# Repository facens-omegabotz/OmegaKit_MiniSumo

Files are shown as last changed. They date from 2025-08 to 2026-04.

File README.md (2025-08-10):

# OmegaKit MiniSumo

Repositório dedicado aos projetos de placas de circuito impresso (PCI) desenvolvidas para a categoria Mini Sumô - 500g (Autônomo | RC).

## OmegaKit FX50

Esta pasta diz respeito à versão da placa desenhada para os sensores FX50, da Fox Dynamics. A principal diferença deste desenho para o OmegaKit_RZ60 é a presença de LEDs para a sinalização de recepção de sinal.

[Datasheet FX50](https://github.com/luisf18/FXDevices/blob/main/Sensor_FXS50/Datasheet_FX_S50.pdf)

[Projeto esquemático OmegaKit FX50](./OmegaKit_FX50/OmegaKit_FX50.pdf)

## OmegaKit RZ60

Esta pasta diz respeito à versão da placa desenhada para os sensores RZ60s, da Sumozade. Esta placa liga diretamente os sensores à placa, visto que há LEDs na parte de trás dos sensores para sinalização de detecção.

[Informações RZ60s](https://sumozade.com/rz60s-digital-infrared-sensor--0-60-cm-)

[Projeto esquemático OmegaKit RZ60](./OmegaKit_RZ60/OmegaKit_RZ60.pdf)

## Omegakit Junior

Esta pasta diz respeito à versão da placa dedicada à nova categoria de mini sumô autônomo para juniores. Ela utiliza um Arduino Nano ao invés de um ESP32 DEVKIT V1, e possui 5 entradas analógicas para uso, visto que o Arduino Nano pode converter entradas analógicas em digitais de acordo com a necessidade.

[Projeto esquemático OmegaKit Junior](./OmegaKit_Junior/OmegaKit_Junior.pdf)

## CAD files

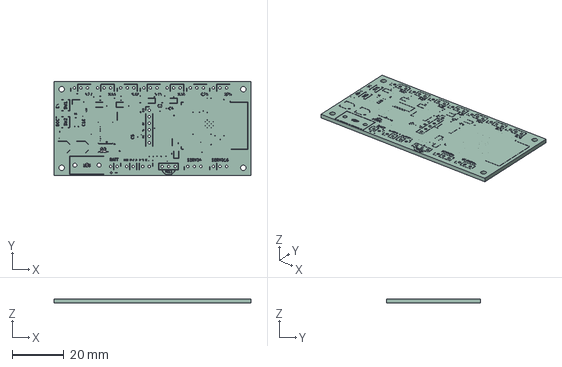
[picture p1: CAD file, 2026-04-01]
OmegaKit_ESP_Embarcado_Simplificado/OmegaKit_ESP_Embarcado_Simplificado.step
76.5 x 36.5 x 1.58 mm
OmegaKit_ESP_Embarcado_Simplificado_silkscreen
OmegaKit_ESP_Embarcado_Simplificado_PCB

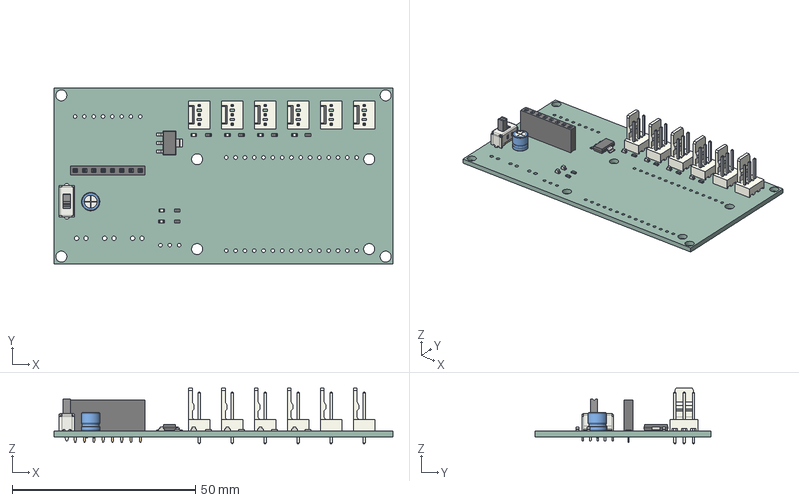
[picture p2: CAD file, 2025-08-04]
OmegaKit_FX50/OmegaKit_FX50.step
92.5 x 48.0 x 15.3 mm
Molex_KK-254_AE-6410-03A_1x03_P2.54mm_Vertical x 6
PinSocket_1x08_P2.54mm_Vertical
LED_0603_1608Metric x 6
R_0603_1608Metric x 6
SOT-223
C_Radial_D5.0mm_H5.0mm_P2.00mm
SW_Slide_SPDT_Straight_CK_OS102011MS2Q
OmegaKit_FX50_PCB

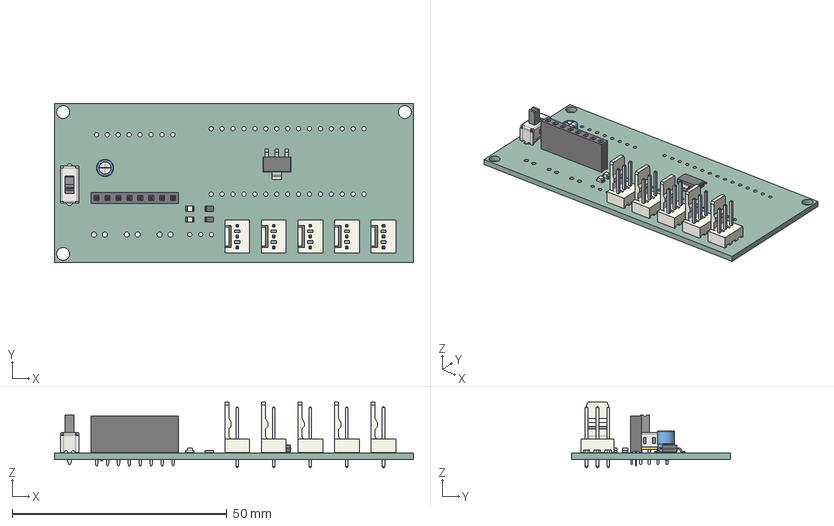
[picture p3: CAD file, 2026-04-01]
OmegaKit_Junior/OmegaKit_Junior.step
83.5 x 37.0 x 15.3 mm
LED_0805_2012Metric x 2
R_0805_2012Metric x 2
Molex_KK-254_AE-6410-03A_1x03_P2.54mm_Vertical x 5
SW_Slide_SPDT_Straight_CK_OS102011MS2Q
PinSocket_1x08_P2.54mm_Vertical
C_Radial_D4.0mm_H5.0mm_P1.50mm
SOT-223
OmegaKit_Junior_PCB

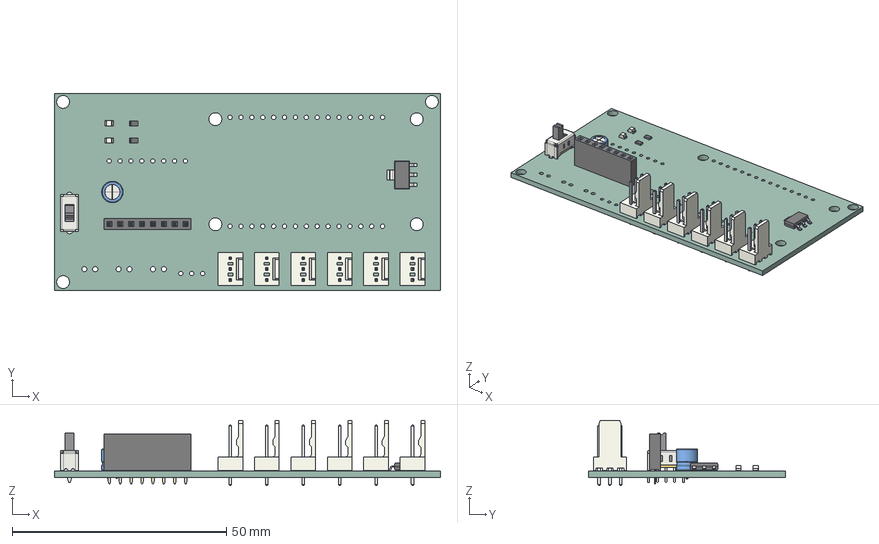
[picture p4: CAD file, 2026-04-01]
OmegaKit_RZ60/OmegaKit_RZ60.step
90.0 x 46.0 x 15.3 mm
Molex_KK-254_AE-6410-03A_1x03_P2.54mm_Vertical x 6
SW_Slide_SPDT_Straight_CK_OS102011MS2Q
PinSocket_1x08_P2.54mm_Vertical
LED_0805_2012Metric x 2
C_Radial_D5.0mm_H5.0mm_P2.00mm
R_0805_2012Metric x 2
SOT-223
OmegaKit_RZ60_PCB

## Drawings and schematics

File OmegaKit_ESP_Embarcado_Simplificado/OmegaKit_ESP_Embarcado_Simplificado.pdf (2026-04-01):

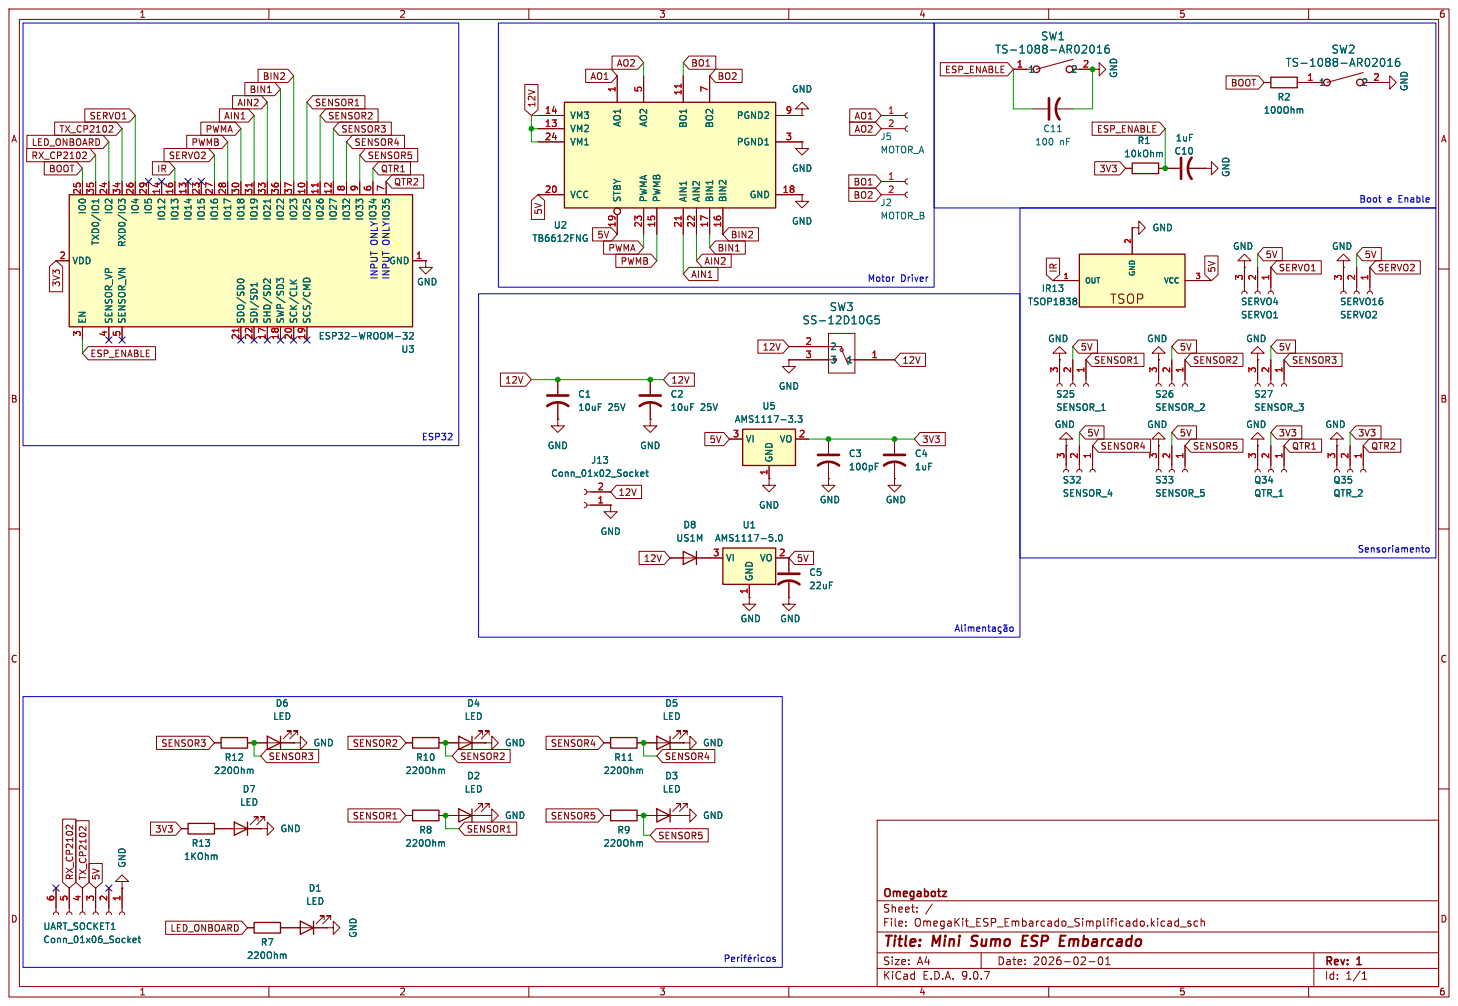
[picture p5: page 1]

5 SDO/SD0 21 SDI/SD1 22 SHD/SD2 17 SWP/SD3 18 SCK/CLK 20 SCS/CMD 19 VDD 2 GND 1 IO0 25 TXD0/IO1 35 IO2 24 RXD0/IO3 34 IO4 26 IO5 29 IO12 14 IO13 16 IO14 13 IO15 23 IO16 27 IO17 28 IO18 30 IO19 31 IO21 33 IO22 36 IO23 37 IO25 10 IO26 11 IO27 12 IO32

þÿAlimentação INPUT ONLY INPUT ONLY GND

Id: 1/1 Title: Mini Sumo ESP Embarcado

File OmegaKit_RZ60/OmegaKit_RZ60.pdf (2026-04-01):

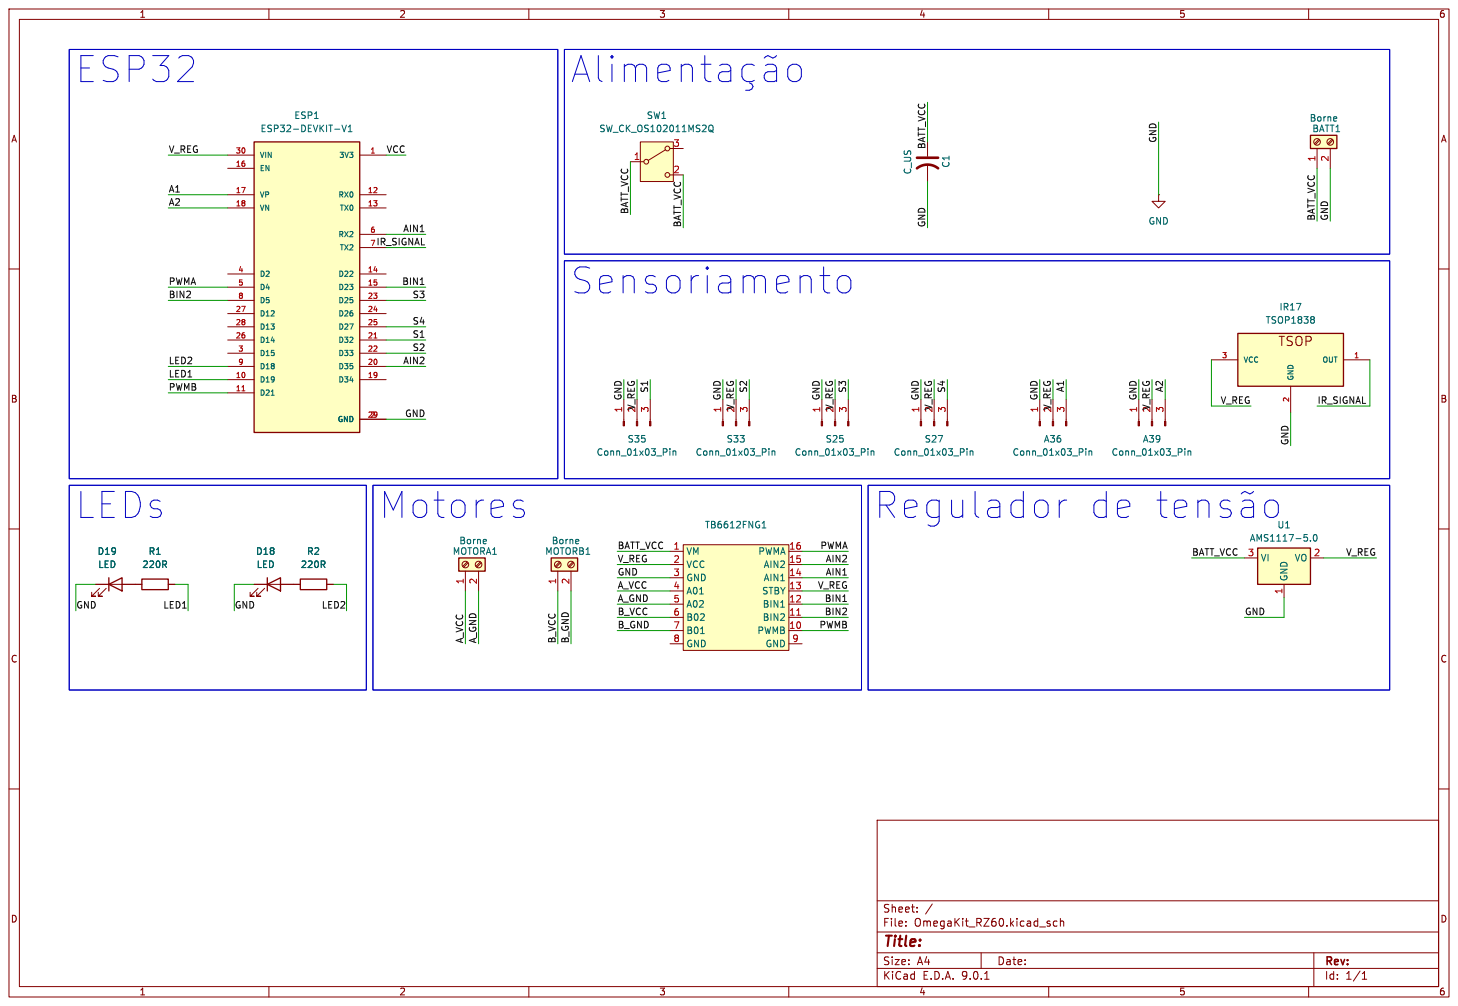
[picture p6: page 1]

2 MOTORA1 Borne VM 1 VCC 2 GND 3 A01 4 A02 5 B02 6 B01 7 GND 8 PWMA 16 AIN2 15 AIN1 14 STBY 13 BIN1 12 BIN2 11 PWMB 10 GND 9 TB6612FNG1 GND
Sensoriamento

Id: 1/1 Title: File: OmegaKit_RZ60.kicad_sch Sheet: / 1

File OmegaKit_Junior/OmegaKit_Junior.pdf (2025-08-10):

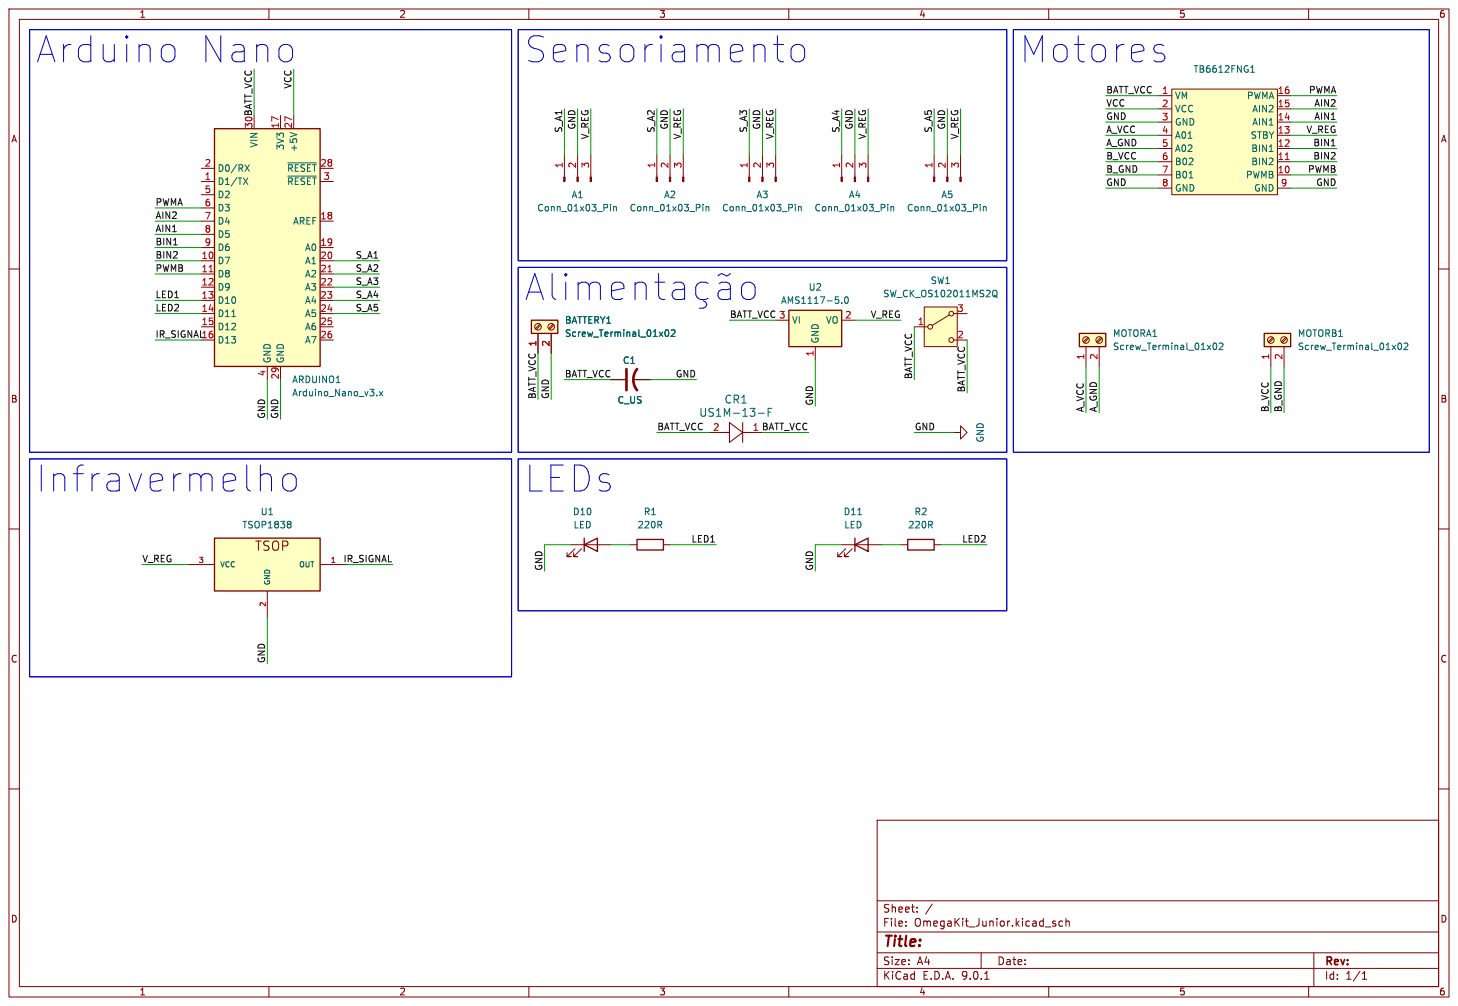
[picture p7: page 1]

2 MOTORB1 Screw_Terminal_01x02 VM 1 VCC 2 GND 3 A01 4 A02 5 B02 6 B01 7 GND 8 PWMA 16 AIN2 15 AIN1 14 STBY 13 BIN1 12 BIN2 11 PWMB 10 GND 9 TB6612FNG1 R1

3 A2 Conn_01x03_Pin D0/RX 2 D1/TX 1 D2 5 D3 6 D4 7 D5 8 D6 9 D7 10 D8 11 D9 12 D10 13 D11 14 D12 15 D13 16 VIN 30 GND

Id: 1/1 Title: File: OmegaKit_Junior.kicad_sch Sheet: /

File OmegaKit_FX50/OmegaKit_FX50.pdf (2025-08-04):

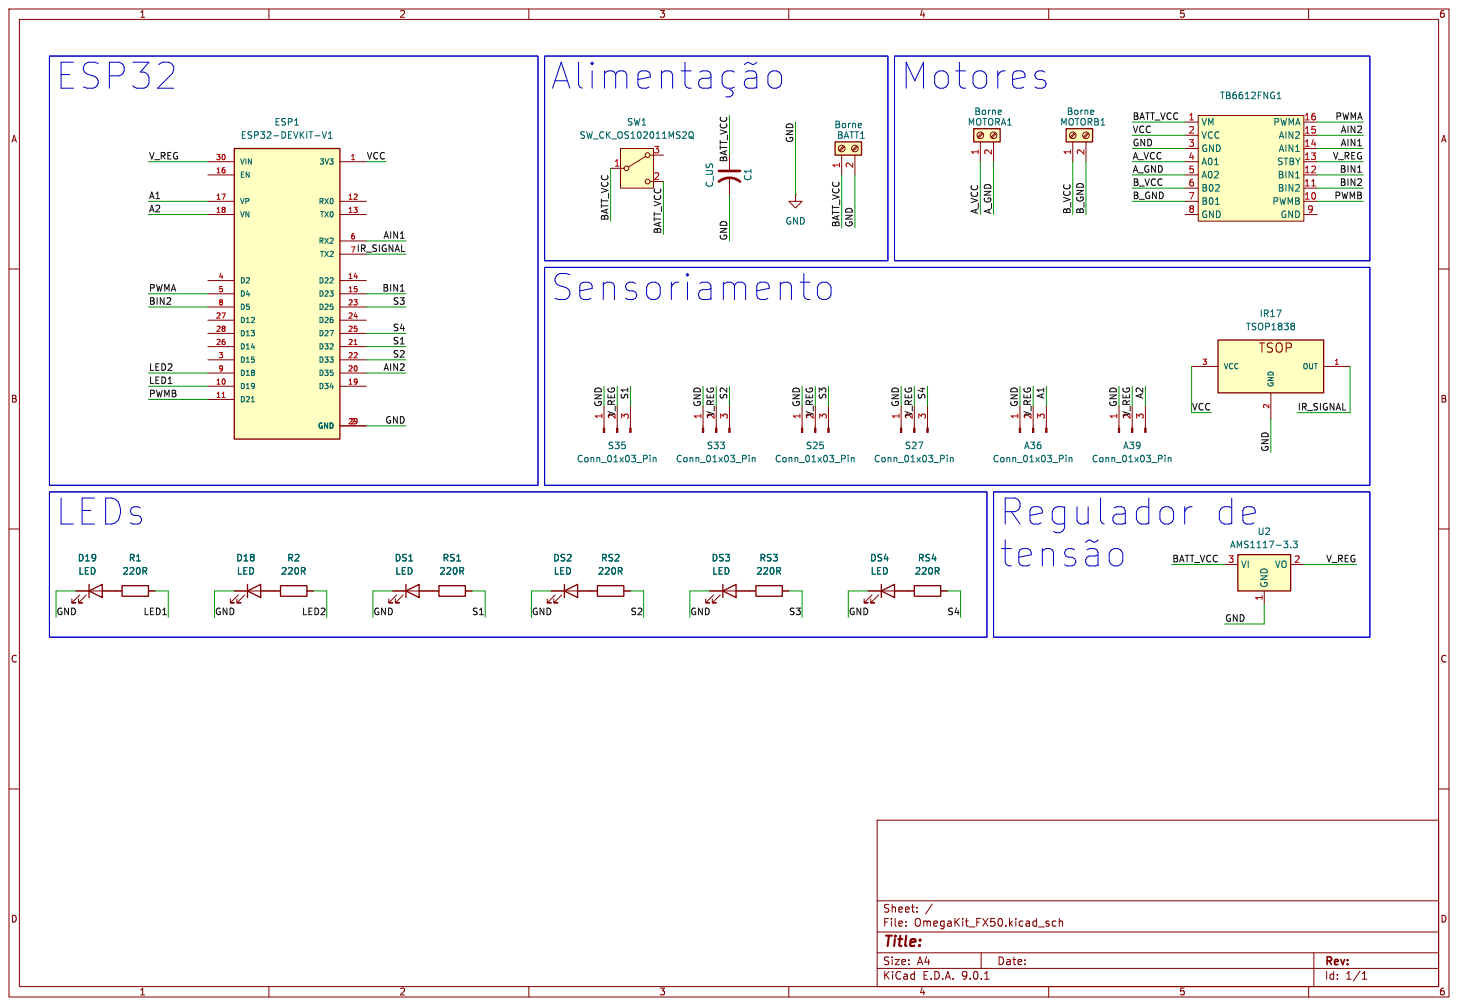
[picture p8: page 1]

2 MOTORB1 Borne VM 1 VCC 2 GND 3 A01 4 A02 5 B02 6 B01 7 GND 8 PWMA 16 AIN2 15 AIN1 14 STBY 13 BIN1 12 BIN2 11 PWMB 10 GND 9 TB6612FNG1

Id: 1/1 Title: File: OmegaKit_FX50.kicad_sch Sheet: / DS2
LED

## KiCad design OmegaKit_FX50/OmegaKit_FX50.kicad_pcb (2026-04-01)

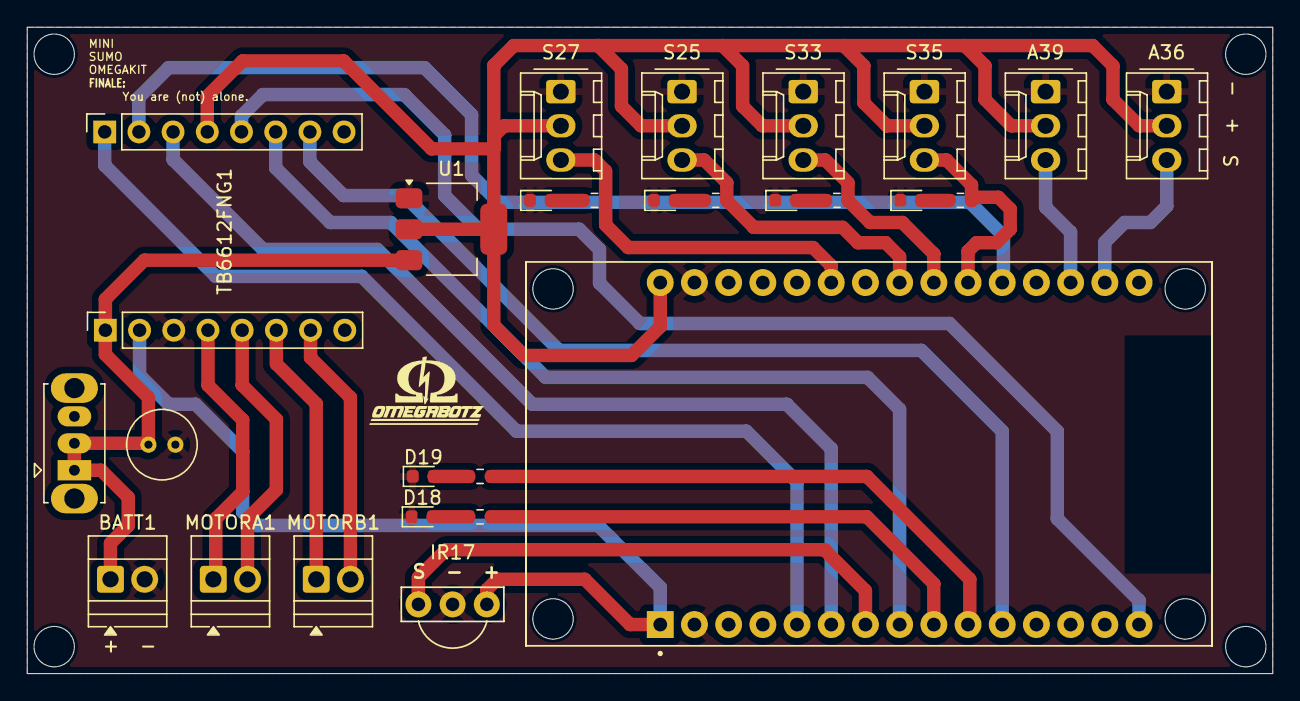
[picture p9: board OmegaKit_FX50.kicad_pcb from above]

Board: 2 copper layers, 92.5 x 48.0 mm, 27 parts (0 on the bottom side), 29 nets.

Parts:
A36, A39: Conn_01x03_Pin; Molex_KK-254_AE-6410-03A_1x03_P2.54mm_Vertical
BATT1: Borne; TerminalBlock_Xinya_XY308-2.54-2P_1x02_P2.54mm_Horizontal
C1: C_US; C_Radial_D5.0mm_H5.0mm_P2.00mm
D18, D19: LED; LED_0603_1608Metric
DS1, DS2, DS3, DS4: LED; LED_0603_1608Metric
ESP1: ESP32-DEVKIT-V1; MODULE_ESP32_DEVKIT_V1
IR17: TSOP1838
MOTORA1: Borne; TerminalBlock_Xinya_XY308-2.54-2P_1x02_P2.54mm_Horizontal
MOTORB1: Borne; TerminalBlock_Xinya_XY308-2.54-2P_1x02_P2.54mm_Horizontal
R1, R2: 220R; R_0603_1608Metric
RS1, RS2, RS3, RS4: 220R; R_0603_1608Metric
S25, S27, S33, S35: Conn_01x03_Pin; Molex_KK-254_AE-6410-03A_1x03_P2.54mm_Vertical
SW1: SW_CK_OS102011MS2Q; SW_Slide_SPDT_Straight_CK_OS102011MS2Q
TB6612FNG1: Socket_TB6612FNG
U1: AMS1117-5.0; SOT-223-3_TabPin2

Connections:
/A1: A36.3, ESP1.17 (VP)
/A2: A39.3, ESP1.18 (VN)
/AIN1: ESP1.6 (RX2), TB6612FNG1.14 (AIN1)
/AIN2: ESP1.20 (D35), TB6612FNG1.15 (AIN2)
/A_GND: MOTORA1.2, TB6612FNG1.5 (A02)
/A_VCC: MOTORA1.1, TB6612FNG1.4 (A01)
/BATT_VCC: BATT1.1, C1.1, SW1.1 (B), SW1.2 (C), TB6612FNG1.1 (VM), U1.3 (VI)
/BIN1: ESP1.15 (D23), TB6612FNG1.12 (BIN1)
/BIN2: ESP1.8 (D5), TB6612FNG1.11 (BIN2)
/B_GND: MOTORB1.2, TB6612FNG1.7 (B01)
/B_VCC: MOTORB1.1, TB6612FNG1.6 (B02)
/IR_SIGNAL: ESP1.7 (TX2), IR17.1 (OUT)
/LED1: ESP1.10 (D19), R1.2
/LED2: ESP1.9 (D18), R2.2
/PWMA: ESP1.5 (D4), TB6612FNG1.16 (PWMA)
/PWMB: ESP1.11 (D21), TB6612FNG1.10 (PWMB)
/S1: ESP1.21 (D32), RS1.2, S35.3
/S2: ESP1.22 (D33), RS2.2, S33.3
/S3: ESP1.23 (D25), RS3.2, S25.3
/S4: ESP1.25 (D27), RS4.2, S27.3
/VCC: ESP1.1 (3V3), IR17.3 (VCC), TB6612FNG1.2 (VCC)
/V_REG: A36.2, A39.2, ESP1.30 (VIN), S25.2, S27.2, S33.2, S35.2, TB6612FNG1.13 (STBY), U1.2 (VO)
GND: A36.1, A39.1, BATT1.2, C1.2, D18.1 (K), D19.1 (K), DS1.1 (K), DS2.1 (K), DS3.1 (K), DS4.1 (K), ESP1.2 (GND), ESP1.29 (GND), IR17.2 (GND), S25.1, S27.1, S33.1, S35.1, TB6612FNG1.3 (GND), U1.1 (GND)
unnamed: D18.2 (A), R2.1
unnamed: D19.2 (A), R1.1
unnamed: DS1.2 (A), RS1.1
unnamed: DS2.2 (A), RS2.1
unnamed: DS3.2 (A), RS3.1
unnamed: DS4.2 (A), RS4.1

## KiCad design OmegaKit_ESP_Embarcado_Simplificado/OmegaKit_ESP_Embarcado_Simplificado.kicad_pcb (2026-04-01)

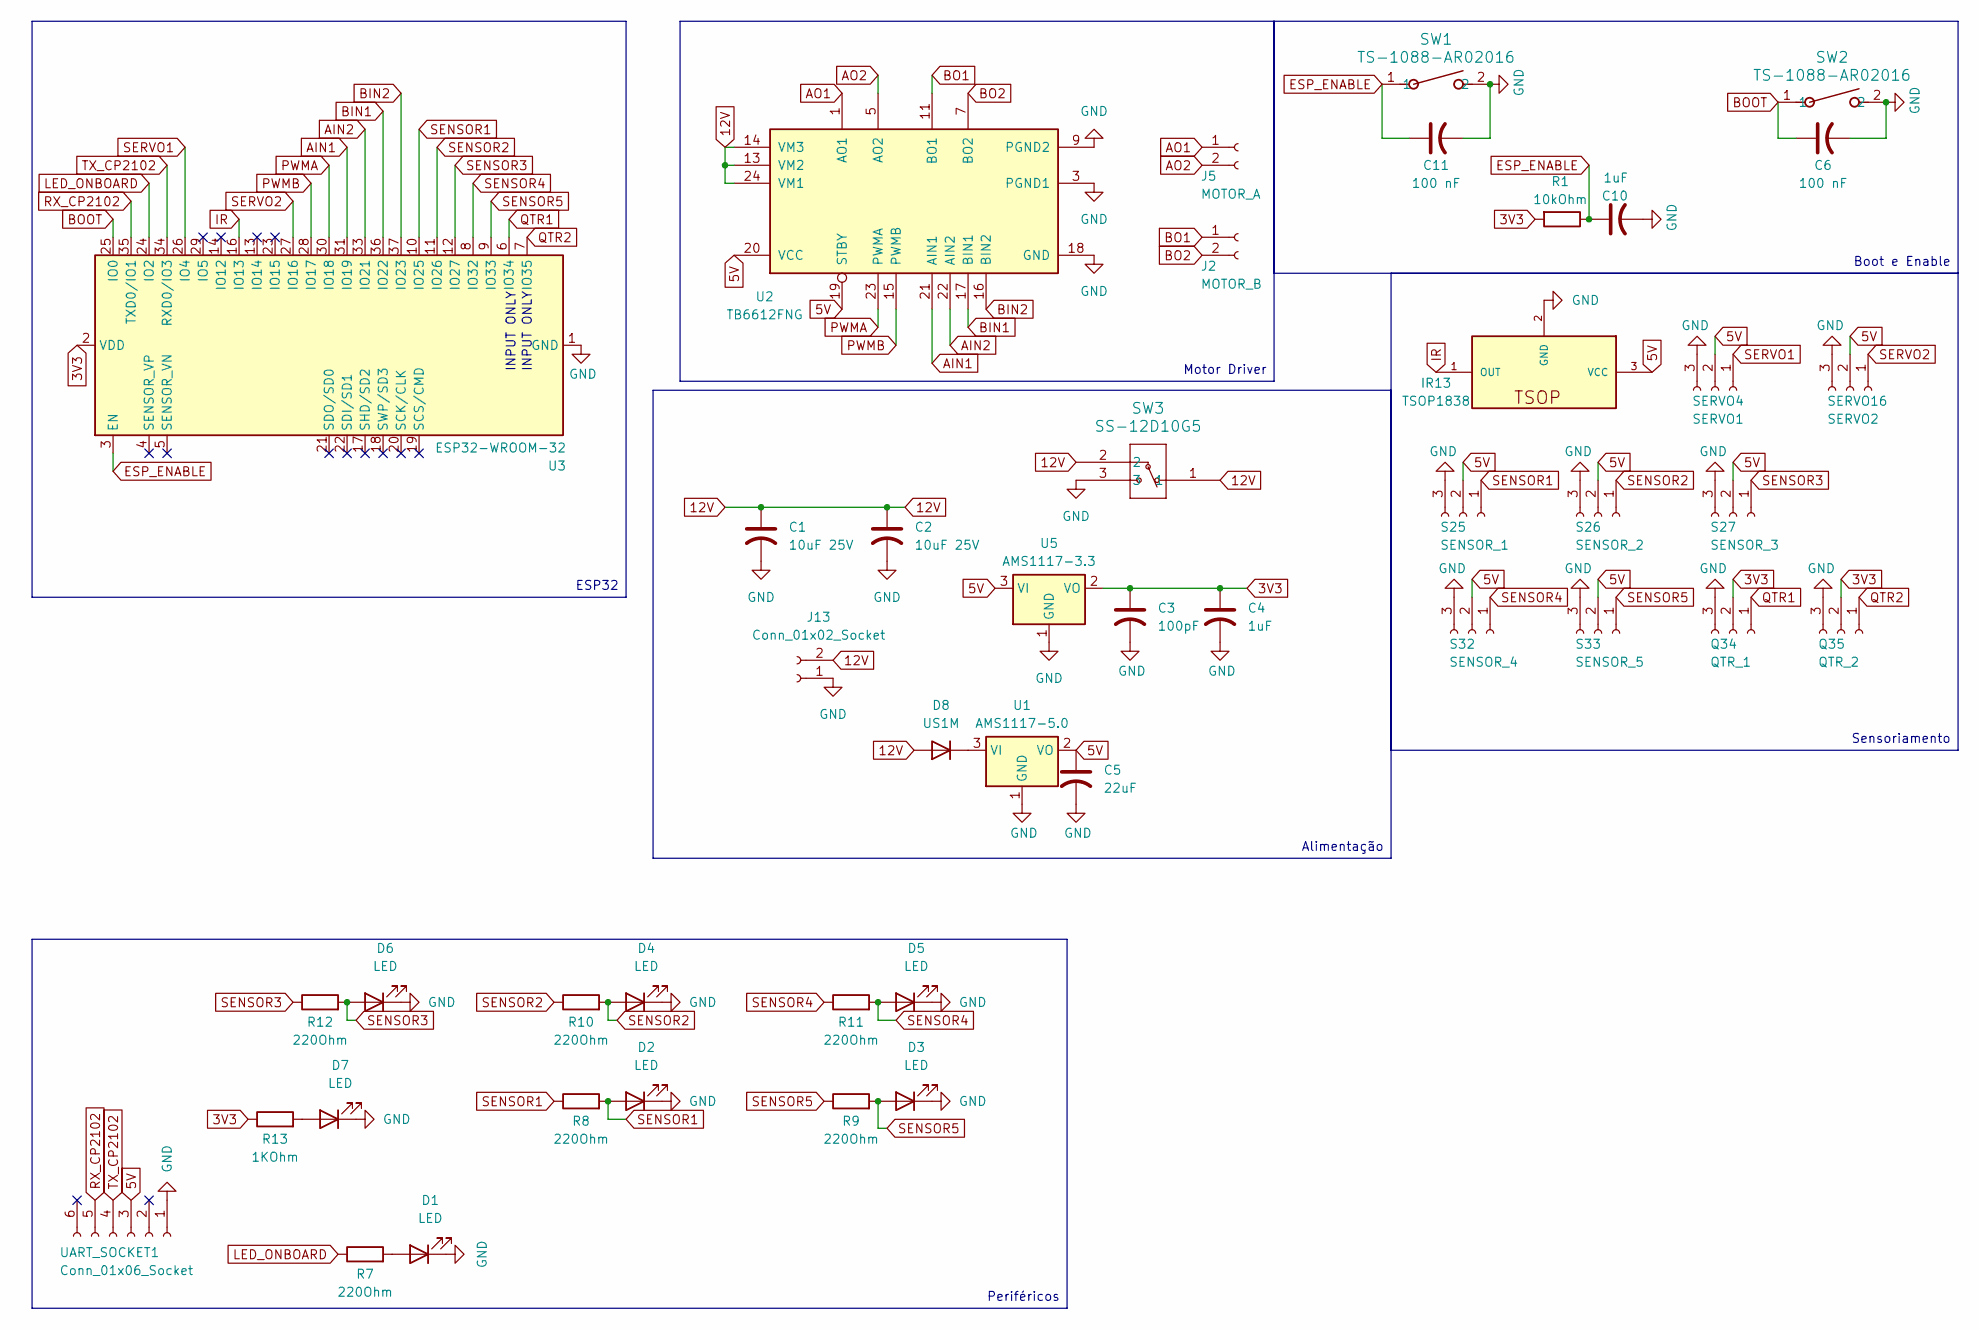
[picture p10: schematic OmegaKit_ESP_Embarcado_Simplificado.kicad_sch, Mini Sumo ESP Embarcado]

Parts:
C1, C2: 10uF 25V; C_Elec_4x5.4
C3: 100pF; C_0603_1608Metric_Pad1.08x0.95mm_HandSolder
C4, C10: 1uF; C_0402_1005Metric_Pad0.74x0.62mm_HandSolder
C5: 22uF; C_0603_1608Metric_Pad1.08x0.95mm_HandSolder
C6, C11: 100 nF; C_0201_0603Metric_Pad0.64x0.40mm_HandSolder
D1, D2, D3, D4, D5, D6, D7: LED; LED_0805_2012Metric_Pad1.15x1.40mm_HandSolder
D8: US1M; D_SMA_Handsoldering
IR13: TSOP1838
J2: MOTOR_B; PinHeader_1x02_P2.54mm_Vertical
J5: MOTOR_A; PinHeader_1x02_P2.54mm_Vertical
J13: Conn_01x02_Socket; PinHeader_1x02_P2.54mm_Vertical
Q34: QTR_1; PinHeader_1x03_P2.54mm_Vertical
Q35: QTR_2; PinHeader_1x03_P2.54mm_Vertical
R1: 10kOhm; R_0603_1608Metric_Pad0.98x0.95mm_HandSolder
R7, R8, R9, R10, R11, R12: 220Ohm; R_0805_2012Metric_Pad1.20x1.40mm_HandSolder
R13: 1KOhm; R_0805_2012Metric_Pad1.20x1.40mm_HandSolder
S25: SENSOR_1; PinHeader_1x03_P2.54mm_Vertical
S26: SENSOR_2; PinHeader_1x03_P2.54mm_Vertical
S27: SENSOR_3; PinHeader_1x03_P2.54mm_Vertical
S32: SENSOR_4; PinHeader_1x03_P2.54mm_Vertical
S33: SENSOR_5; PinHeader_1x03_P2.54mm_Vertical
SERVO4: SERVO1; PinHeader_1x03_P2.54mm_Vertical
SERVO16: SERVO2; PinHeader_1x03_P2.54mm_Vertical
SW1, SW2: TS-1088-AR02016; SW_TS-1088_XNP
SW3: SS-12D10G5; SS-12D10G5_XKB
U1: AMS1117-5.0; SOT-223-3_TabPin2
U2: TB6612FNG; SSOP-24_5.3x8.2mm_P0.65mm
U3: ESP32-WROOM-32
U5: AMS1117-3.3; SOT-223-3_TabPin2
UART_SOCKET1: Conn_01x06_Socket; PinHeader_1x06_P2.54mm_Vertical

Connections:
3V3: C3.1, C4.1, Q34.2, Q35.2, R1.2, R13.1, U3.2 (VDD), U5.2 (VO)
5V: C5.1, IR13.3 (VCC), S25.2, S26.2, S27.2, S32.2, S33.2, SERVO4.2, SERVO16.2, U1.2 (VO), U2.19 (STBY), U2.20 (VCC), U5.3 (VI), UART_SOCKET1.3
12V: C1.1, C2.1, D8.2 (A), J13.2, SW3.1, SW3.2, U2.13 (VM2), U2.14 (VM3), U2.24 (VM1)
AIN1: U2.21 (AIN1), U3.31 (IO19)
AIN2: U2.22 (AIN2), U3.33 (IO21)
AO1: J5.1, U2.1 (AO1), U2.2 (AO1)
AO2: J5.2, U2.5 (AO2), U2.6 (AO2)
BIN1: U2.17 (BIN1), U3.36 (IO22)
BIN2: U2.16 (BIN2), U3.37 (IO23)
BO1: J2.1, U2.11 (BO1), U2.12 (BO1)
BO2: J2.2, U2.7 (BO2), U2.8 (BO2)
BOOT: C6.1, SW2.1, U3.25 (IO0)
ESP_ENABLE: C10.1, C11.1, R1.1, SW1.1, U3.3 (EN)
GND: C1.2, C2.2, C3.2, C4.2, C5.2, C6.2, C10.2, C11.2, D1.1 (K), D2.1 (K), D3.1 (K), D4.1 (K), D5.1 (K), D6.1 (K), D7.1 (K), IR13.2 (GND), J13.1, Q34.3, Q35.3, S25.3, S26.3, S27.3, S32.3, S33.3, SERVO4.3, SERVO16.3, SW1.2, SW2.2, SW3.3, U1.1 (GND), U2.3 (PGND1), U2.4 (PGND1), U2.9 (PGND2), U2.10 (PGND2), U2.18 (GND), U3.1 (GND), U3.15 (GND), U3.38 (GND), U3.39 (GND), U5.1 (GND), UART_SOCKET1.1
IR: IR13.1 (OUT), U3.16 (IO13)
LED_ONBOARD: R7.1, U3.24 (IO2)
unnamed: D1.2 (A), R7.2
unnamed: D7.2 (A), R13.2
unnamed: D8.1 (K), U1.3 (VI)
PWMA: U2.23 (PWMA), U3.30 (IO18)
PWMB: U2.15 (PWMB), U3.28 (IO17)
QTR1: Q34.1, U3.6 (IO34)
QTR2: Q35.1, U3.7 (IO35)
RX_CP2102: U3.35 (TXD0/IO1), UART_SOCKET1.5
SENSOR1: D2.2 (A), R8.1, R8.2, S25.1, U3.10 (IO25)
SENSOR2: D4.2 (A), R10.1, R10.2, S26.1, U3.11 (IO26)
SENSOR3: D6.2 (A), R12.1, R12.2, S27.1, U3.12 (IO27)
SENSOR4: D5.2 (A), R11.1, R11.2, S32.1, U3.8 (IO32)
SENSOR5: D3.2 (A), R9.1, R9.2, S33.1, U3.9 (IO33)
SERVO1: SERVO4.1, U3.26 (IO4)
SERVO2: SERVO16.1, U3.27 (IO16)
TX_CP2102: U3.34 (RXD0/IO3), UART_SOCKET1.4

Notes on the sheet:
INPUT ONLY
Motor Driver
Alimentação
Periféricos
Sensoriamento
Boot e Enable
ESP32

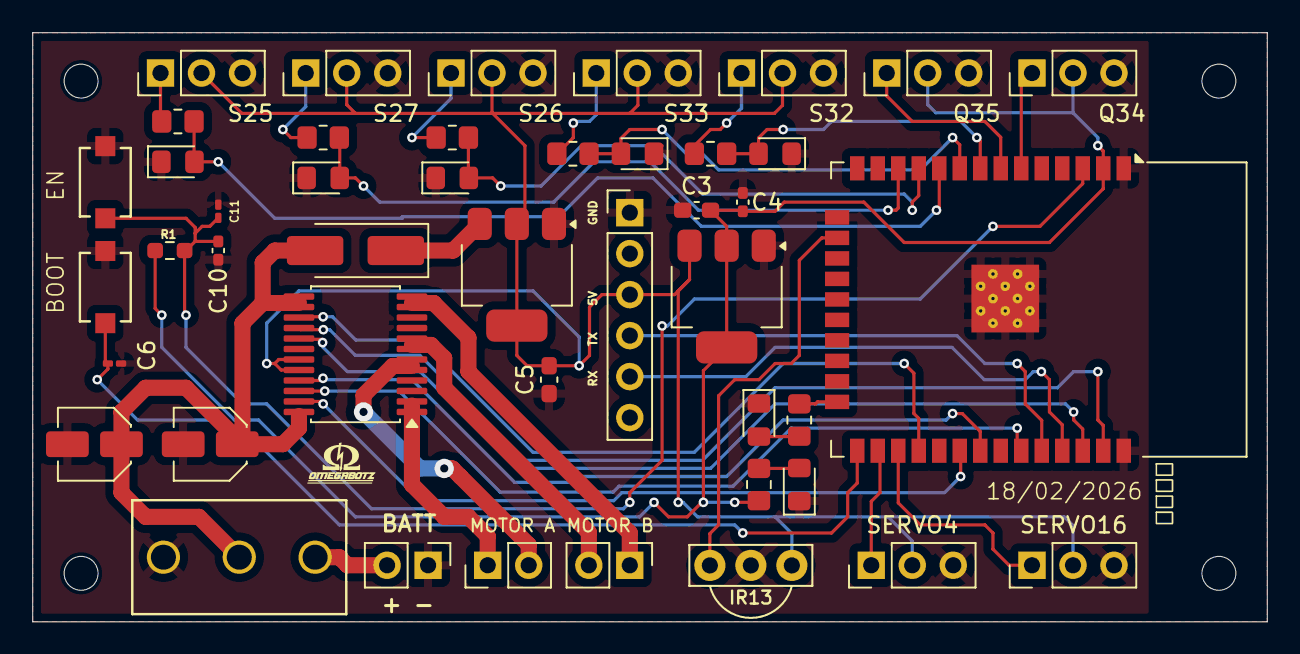
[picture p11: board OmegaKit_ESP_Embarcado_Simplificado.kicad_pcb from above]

Board: 2 copper layers, 76.5 x 36.5 mm, 45 parts (0 on the bottom side), 32 nets.

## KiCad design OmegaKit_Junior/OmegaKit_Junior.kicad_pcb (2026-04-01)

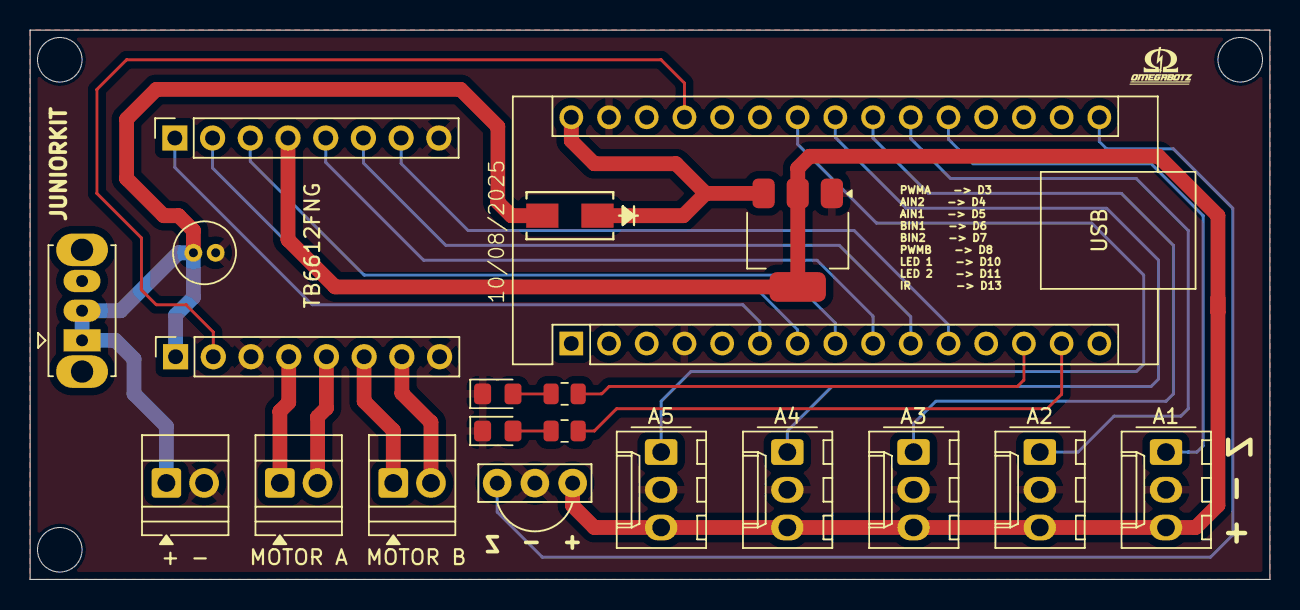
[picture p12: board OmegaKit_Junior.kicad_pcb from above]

Board: 2 copper layers, 83.5 x 37.0 mm, 19 parts (0 on the bottom side), 24 nets.

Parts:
+ -: Screw_Terminal_01x02; TerminalBlock_Xinya_XY308-2.54-2P_1x02_P2.54mm_Horizontal
A1, A2, A3, A4, A5: Conn_01x03_Pin; Molex_KK-254_AE-6410-03A_1x03_P2.54mm_Vertical
ARDUINO1: Arduino_Nano_v3.x; Arduino_Nano
C1: C_US; C_Radial_D4.0mm_H5.0mm_P1.50mm
D10, D11: LED; LED_0805_2012Metric_Pad1.15x1.40mm_HandSolder
MOTOR A: Screw_Terminal_01x02; TerminalBlock_Xinya_XY308-2.54-2P_1x02_P2.54mm_Horizontal
MOTOR B: Screw_Terminal_01x02; TerminalBlock_Xinya_XY308-2.54-2P_1x02_P2.54mm_Horizontal
R1, R2: 220R; R_0805_2012Metric
REG: AMS1117-5.0; SOT-223-3_TabPin2
RET: US1M-13-F; SMA_DIO
SW1: SW_CK_OS102011MS2Q; SW_Slide_SPDT_Straight_CK_OS102011MS2Q
TB6612FNG: Socket_TB6612FNG
U1: TSOP1838

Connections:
/AIN1: ARDUINO1.8 (D5), TB6612FNG.14 (AIN1)
/AIN2: ARDUINO1.7 (D4), TB6612FNG.15 (AIN2)
/A_GND: MOTOR A.2, TB6612FNG.5 (A02)
/A_VCC: MOTOR A.1, TB6612FNG.4 (A01)
/BATT_VCC: + -.1, ARDUINO1.30 (VIN), C1.1, REG.3 (VI), RET.1, RET.2, SW1.1 (B), SW1.2 (C), TB6612FNG.1 (VM)
/BIN1: ARDUINO1.9 (D6), TB6612FNG.12 (BIN1)
/BIN2: ARDUINO1.10 (D7), TB6612FNG.11 (BIN2)
/B_GND: MOTOR B.2, TB6612FNG.7 (B01)
/B_VCC: MOTOR B.1, TB6612FNG.6 (B02)
/IR_SIGNAL: ARDUINO1.16 (D13), U1.1 (OUT)
/LED1: ARDUINO1.13 (D10), R1.2
/LED2: ARDUINO1.14 (D11), R2.2
/PWMA: ARDUINO1.6 (D3), TB6612FNG.16 (PWMA)
/PWMB: ARDUINO1.11 (D8), TB6612FNG.10 (PWMB)
/S_A1: A1.1, ARDUINO1.20 (A1)
/S_A2: A2.1, ARDUINO1.21 (A2)
/S_A3: A3.1, ARDUINO1.22 (A3)
/S_A4: A4.1, ARDUINO1.23 (A4)
/S_A5: A5.1, ARDUINO1.24 (A5)
/VCC: ARDUINO1.27 (+5V), TB6612FNG.2 (VCC)
/V_REG: A1.3, A2.3, A3.3, A4.3, A5.3, REG.2 (VO), TB6612FNG.13 (STBY), U1.3 (VCC)
GND: + -.2, A1.2, A2.2, A3.2, A4.2, A5.2, ARDUINO1.4 (GND), ARDUINO1.29 (GND), C1.2, D10.1 (K), D11.1 (K), REG.1 (GND), TB6612FNG.3 (GND), TB6612FNG.8 (GND), TB6612FNG.9 (GND), U1.2 (GND)
unnamed: D10.2 (A), R1.1
unnamed: D11.2 (A), R2.1

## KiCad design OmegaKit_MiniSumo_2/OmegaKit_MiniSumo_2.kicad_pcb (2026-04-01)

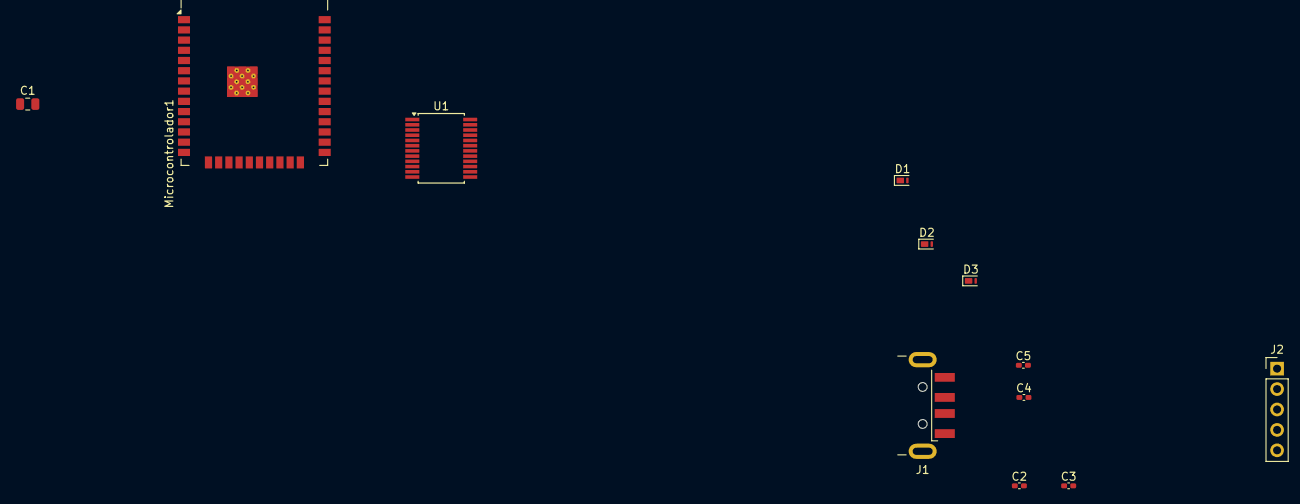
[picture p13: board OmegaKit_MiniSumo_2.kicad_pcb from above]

Board: 2 copper layers, 12 parts (0 on the bottom side), 12 nets, no tracks yet.

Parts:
C1: C_Small_US; C_0805_2012Metric
C2, C4: 4.7uF; C_0402_1005Metric_Pad0.74x0.62mm_HandSolder
C3, C5: .1uf; C_0402_1005Metric_Pad0.74x0.62mm_HandSolder
D1, D2, D3: PTVS5V0Z1USK; Nexperia_DSN1608-2_1.6x0.8mm
J1: USB_A; USB_A_CNCTech_1001-011-01101_Horizontal
J2: Conn_01x05_Pin; PinHeader_1x05_P2.54mm_Vertical
Microcontrolador1: ESP32-WROOM-32E-R2; ESP32-WROOM-32D
U1: TB6612FNG; SSOP-24_5.3x8.2mm_P0.65mm

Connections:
3V3: C1.1, Microcontrolador1.2 (VDD)
3V3_USB: C4.1, C5.1, J2.1
D+: D3.1 (K), J1.3 (D+)
D-: D2.1 (K), J1.2 (D-)
GND: C1.2, C2.2, C3.2, C4.2, C5.2, D1.2 (A), D2.2 (A), D3.2 (A), J1.4 (GND), J1.5 (Shield), J2.4, Microcontrolador1.1 (GND), Microcontrolador1.15 (GND), Microcontrolador1.38 (GND), Microcontrolador1.39 (GND)
unnamed: U1.1 (AO1), U1.2 (AO1)
unnamed: U1.5 (AO2), U1.6 (AO2)
unnamed: U1.11 (BO1), U1.12 (BO1)
unnamed: U1.7 (BO2), U1.8 (BO2)
unnamed: U1.3 (PGND1), U1.4 (PGND1)
unnamed: U1.9 (PGND2), U1.10 (PGND2)
VBUS: C2.1, C3.1, D1.1 (K), J1.1 (VBUS), J2.5

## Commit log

2025-07-26 Ajustes na pinagem para viabilizar uso do ESP32
    [OmegaKit_FX50.kicad_pcb, OmegaKit_FX50.kicad_sch, OmegaKit_FX50.step]
2025-07-26 Atualização do PDF + .step
    [OmegaKit_FX50.step]
2025-07-28 Ajustes regulador de tensão + switch e capacitor + não usar pinoGPIO12
    [OmegaKit_FX50.kicad_pcb, OmegaKit_FX50.kicad_sch]
2025-08-04 Correção de pinos + novas plotagens + modelos step + gerbers
    [OmegaKit_FX50.kicad_pcb, OmegaKit_FX50.step, OmegaKit_RZ60.kicad_pcb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]
2025-08-10 Mudanças RZ60 + Placa juniores
    [OmegaKit_Junior.kicad_pcb, OmegaKit_Junior.kicad_sch, OmegaKit_RZ60.kicad_pcb]
2025-08-10 Registro pinos placa juniores + atualização README.md
    [OmegaKit_Junior.kicad_pcb]
2025-08-10 Novo .step placa juniores
    [OmegaKit_Junior.kicad_pcb, OmegaKit_Junior.step]
2026-02-01 ✨ feat(Omegakit_ESP_Embarcado/*): Inicia novo projeto de eletrônica com ESP-32-WROOM embarcado
    [OmegaKit_ESP_Embarcado.kicad_pcb, OmegaKit_ESP_Embarcado.kicad_sch]
2026-02-04 ✨🚧 feat(Omegakit_ESP_Embarcado/*): Inicia desenho da PCB
    [OmegaKit_ESP_Embarcado.kicad_pcb, OmegaKit_ESP_Embarcado.kicad_sch]
2026-02-08 ✨🚧 feat(OmegaKit_ESP_Embarcado/*): Monta primeira versão da placa, revisa circuitos, remove CP2102
    [OmegaKit_ESP_Embarcado.kicad_pcb, OmegaKit_ESP_Embarcado.kicad_sch]
2026-02-09 ✨ feat(OmegaKit_ESP_Embarcado/*): Adiciona LEDs nos sensores e LED de energia, muda footprint dos capacitores da bateria
    [OmegaKit_ESP_Embarcado.kicad_pcb, OmegaKit_ESP_Embarcado.kicad_sch]
2026-02-09 🧹 chore(OmegaKit_ESP_Embarcado/*): Reorganiza projeto, plota projeto em PDF
    [OmegaKit_ESP_Embarcado.kicad_pcb, OmegaKit_ESP_Embarcado.kicad_sch]
2026-02-13 ✨ feat: Pequenas revisões no esquemático de OmegaKit_ESP_Embarcado/, criação de OmegaKit_ESP_Embarcado_Simplificado/
    [OmegaKit_ESP_Embarcado.kicad_pcb, OmegaKit_ESP_Embarcado_Simplificado.kicad_pcb, OmegaKit_ESP_Embarcado_Simplificado.kicad_sch]
2026-04-01 ✨ feat: atualização de todos os arquivps faltantes
    [OmegaKit_ESP_Embarcado_Simplificado-B_Cu.gbr, OmegaKit_ESP_Embarcado_Simplificado-B_Mask.gbr, OmegaKit_ESP_Embarcado_Simplificado-B_Paste.gbr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]
